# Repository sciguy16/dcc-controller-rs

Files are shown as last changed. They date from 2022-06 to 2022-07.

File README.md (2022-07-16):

# dcc-controller-rs
Open source lightweight DCC controller with firmware written in Rust

Based on the STM32F103C8T6 "blue pill" board - specifically the C8 version
rather than the C6 because the former has 64k of flash, and the graphics
components push the binary size up to around 51k.

DCC controller with an N gauge BR pannier tank

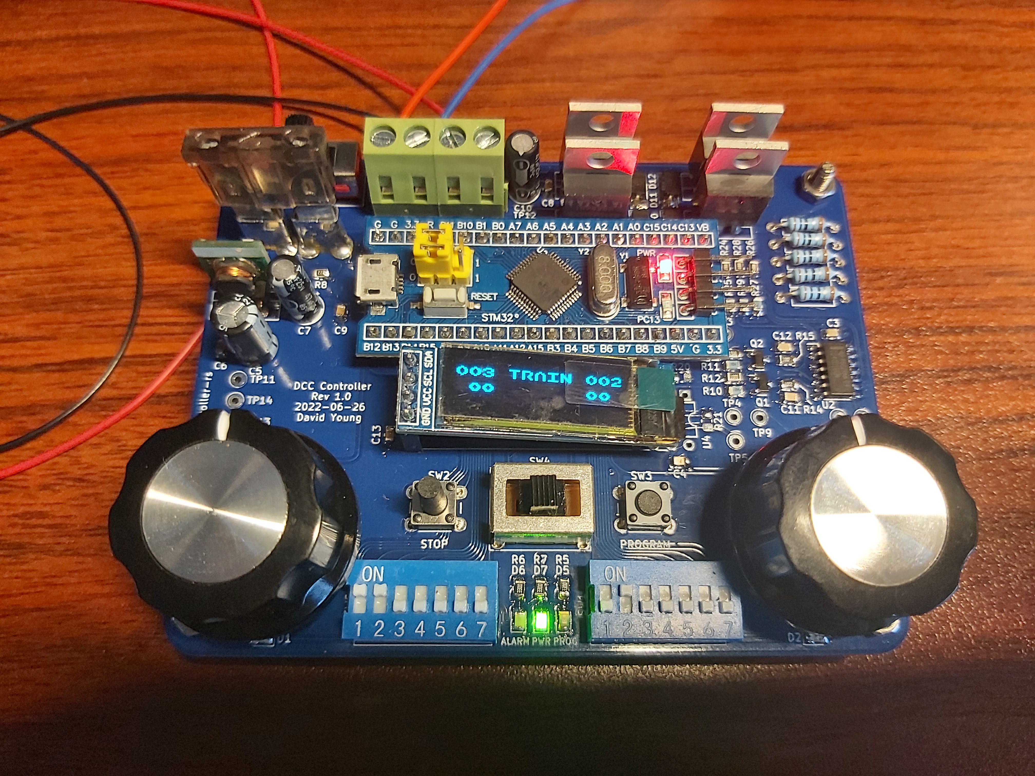
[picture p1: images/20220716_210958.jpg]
Overview of DCC controller


## Features
* Two control potentiometers to control two locomotives, with short-mode
addresses selected via dipswitches
* Potentiometers are centre-off; rotate left to drive the corresponding
locomotive in reverse, and right to drive it forwards
* LED for each channel to show when it is active
* On-off-on mini slide switch to select programming mode
  * programming mode disables all control functions and just sends out
DCC IDLE packets until the "program" button is pressed
  * Controller will then send out the programming sequence to program the
locomotive with the address set on the selected channel
* Current measurement and overcurrent shut-off
* Overcurrent alarm LED
* Screw terminals to connect power supply and track outputs
* Pure-Rust open source firmware based on dcc-rs
* Open source hardware

## Installation
Ensure that the `thumbv7m-none-eabi` target and the `probe-run` tool have
been installed and then `cargo run --release` will automatically flash the
compiled firmware onto the device.

```bash
rustup target add thumbv7m-none-eabi
cargo install probe-run
cargo run --release
DEFMT_LOG=off cargo run --release # Disable defmt logging
```

# License
Source code for the software components is distributed under the terms
of the Mozilla Public License Version 2.0.

Design files for the hardware components are distributed under the terms
of the CERN Open Hardware Licence Version 2 - Weakly Reciprocal.

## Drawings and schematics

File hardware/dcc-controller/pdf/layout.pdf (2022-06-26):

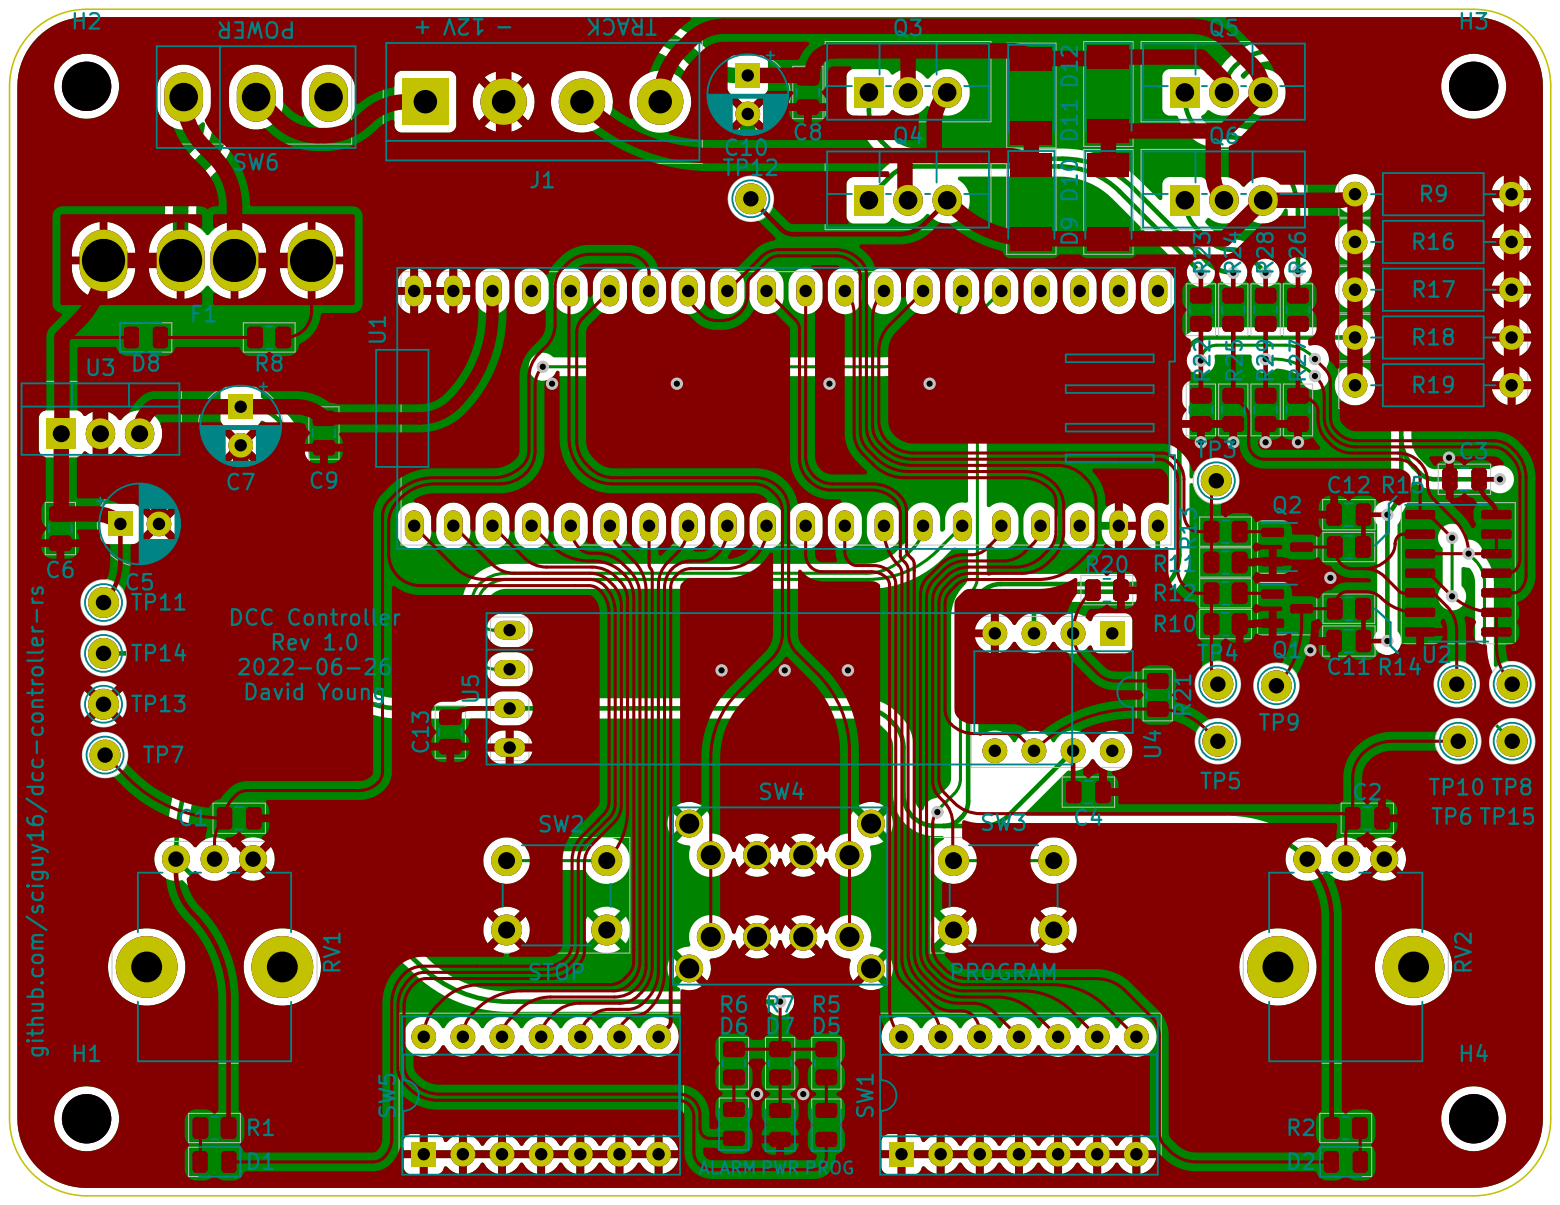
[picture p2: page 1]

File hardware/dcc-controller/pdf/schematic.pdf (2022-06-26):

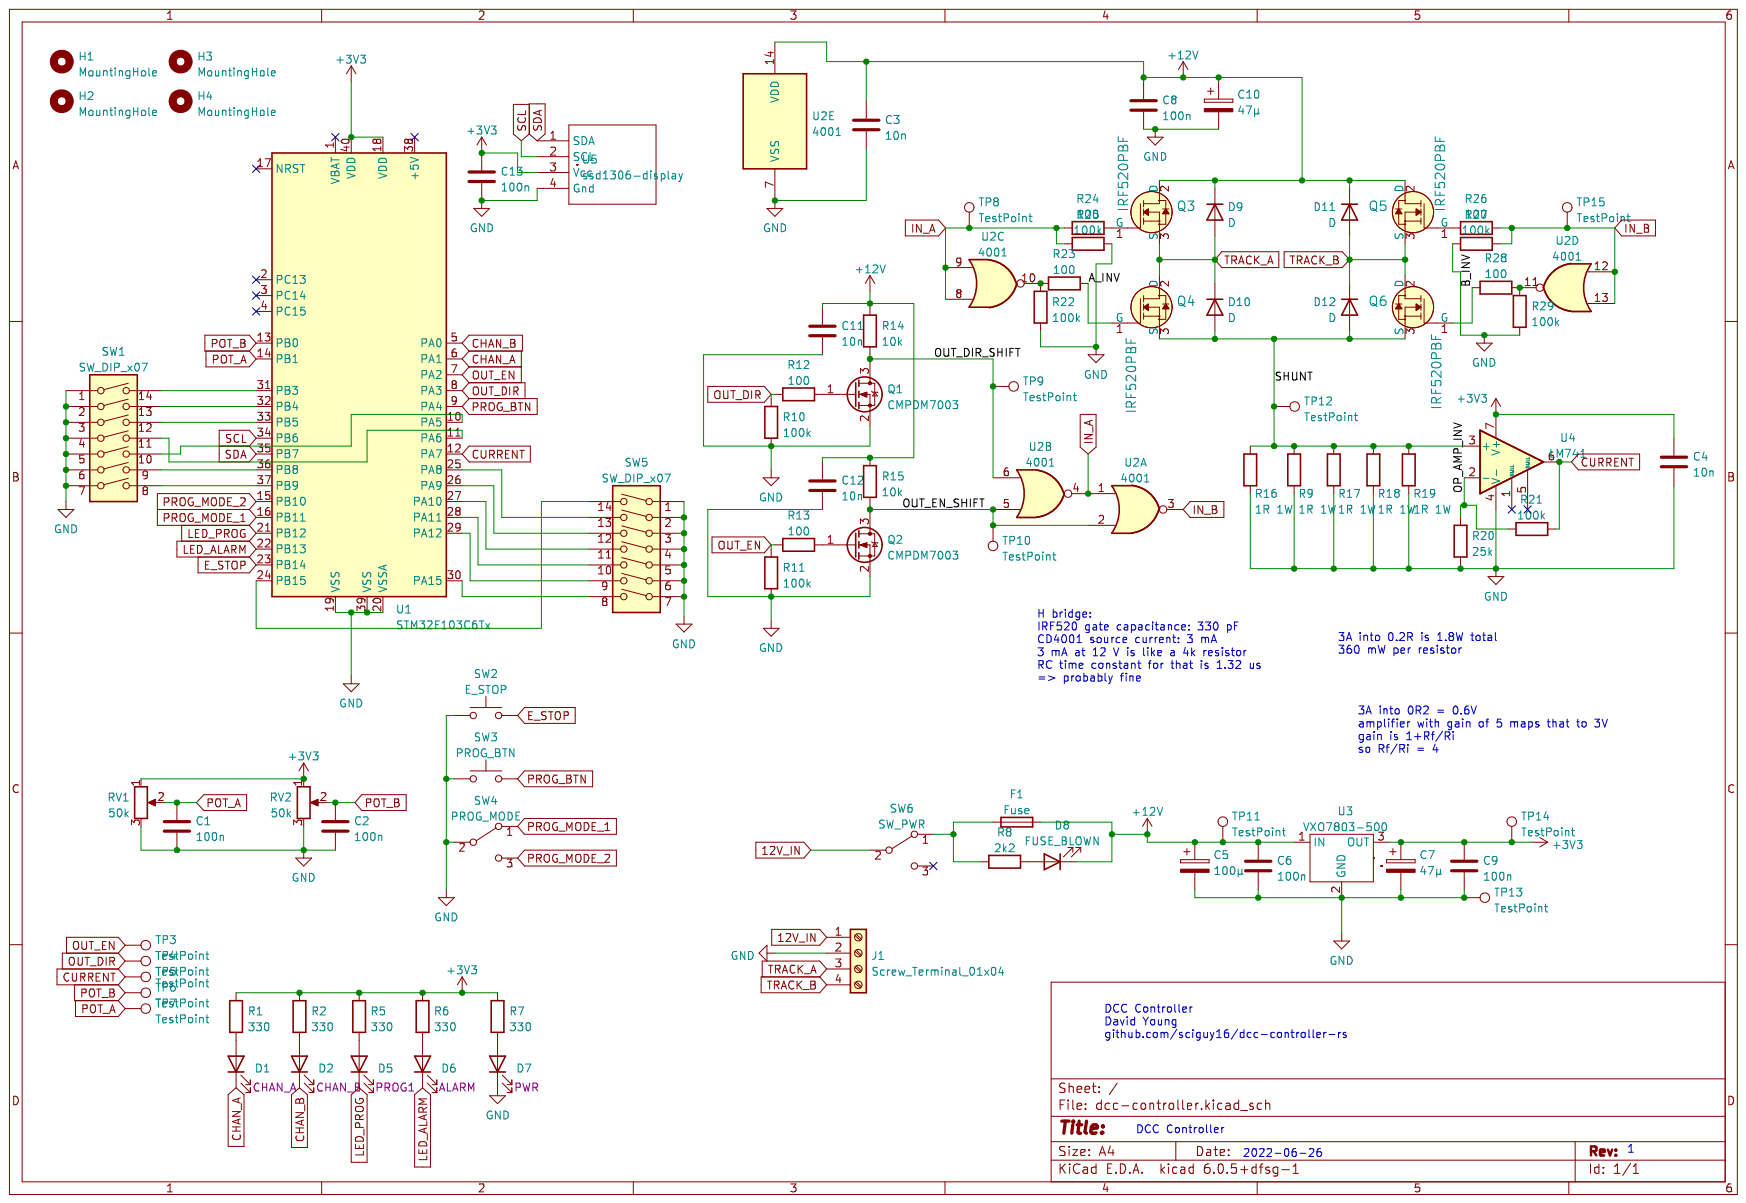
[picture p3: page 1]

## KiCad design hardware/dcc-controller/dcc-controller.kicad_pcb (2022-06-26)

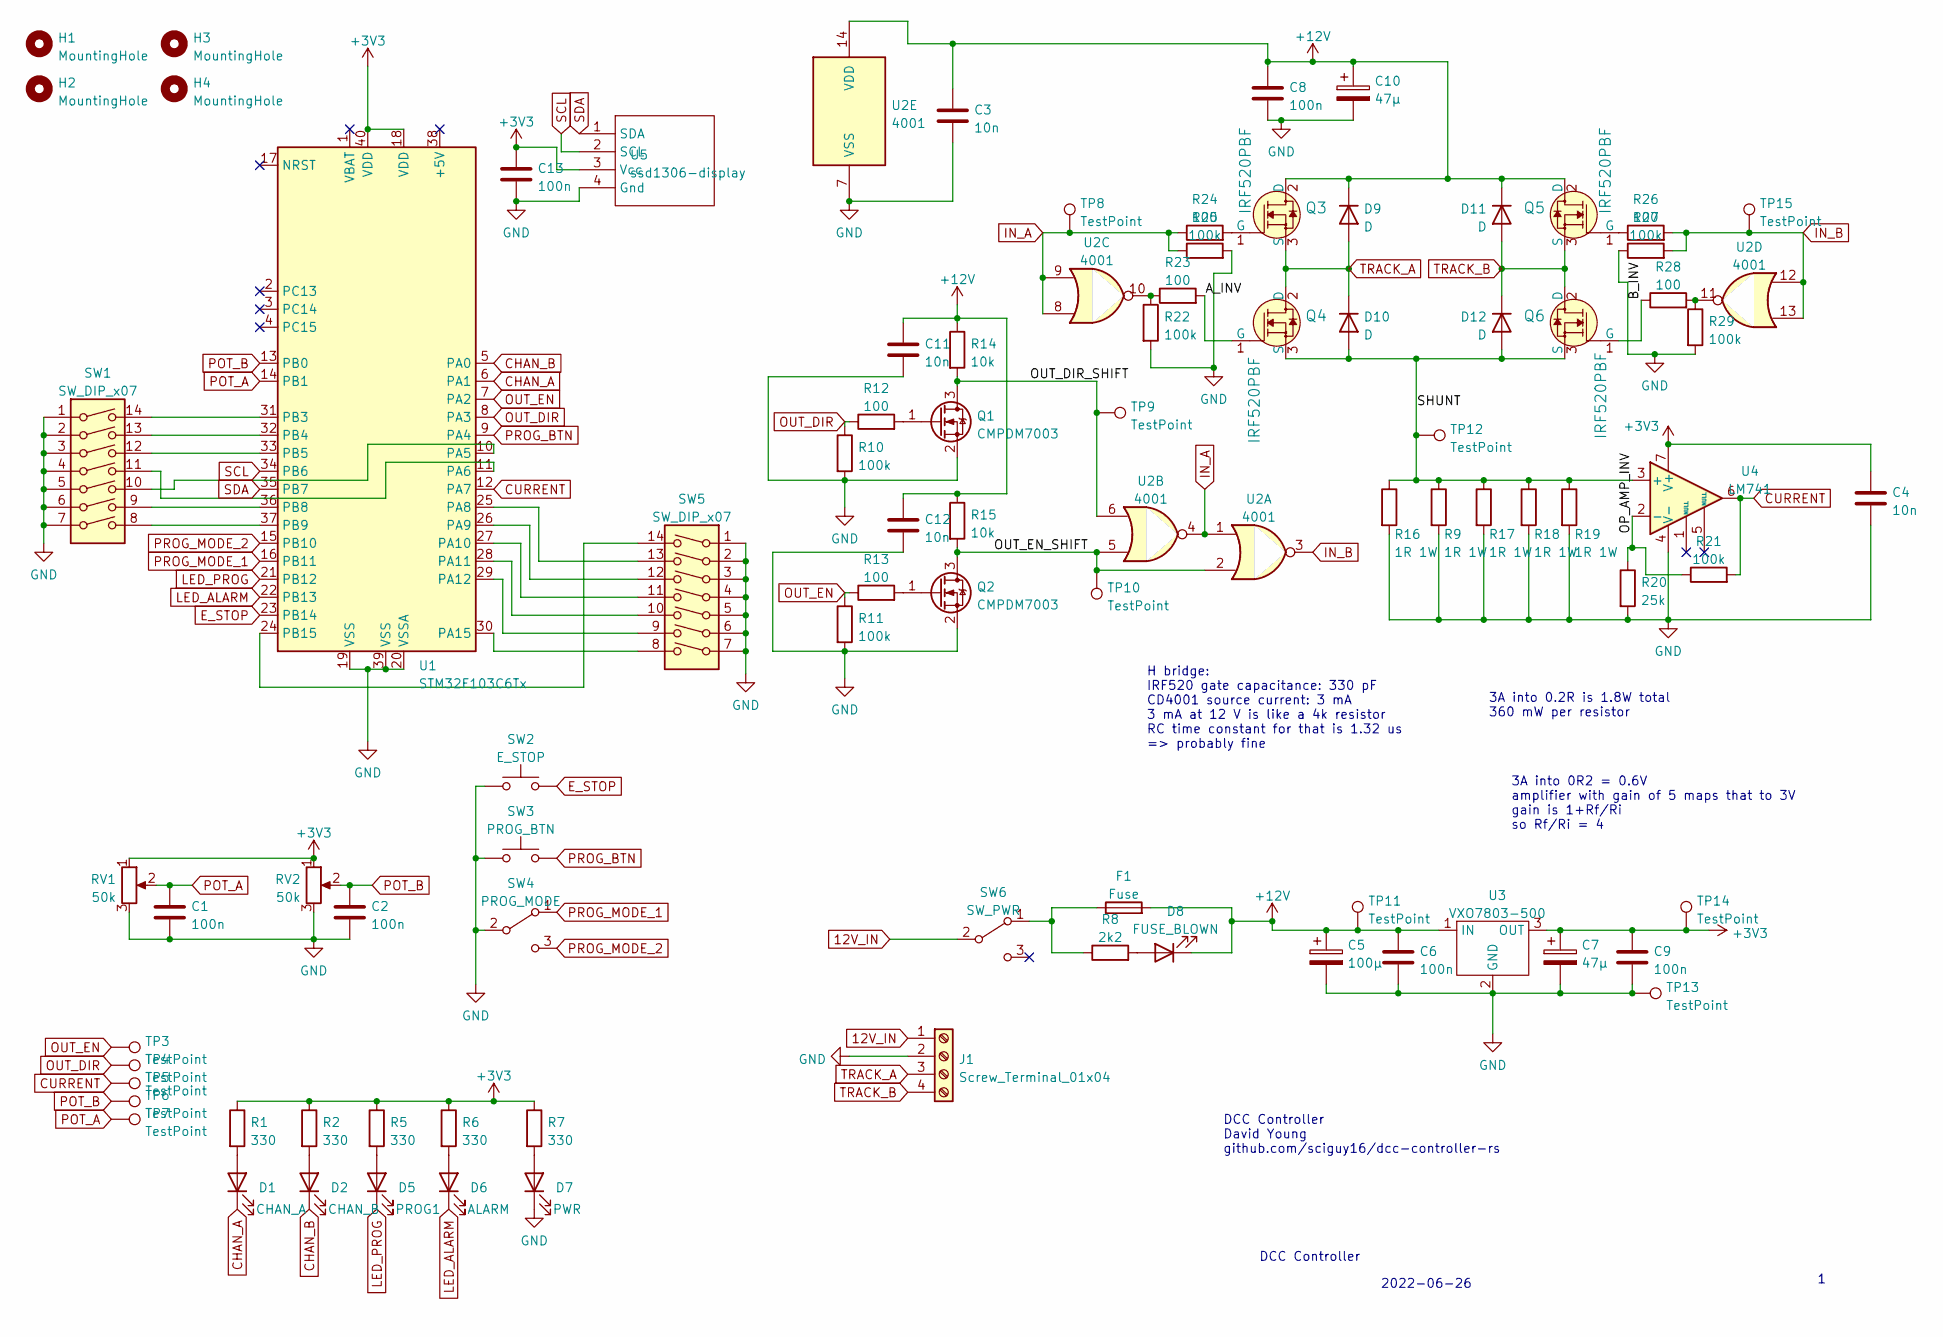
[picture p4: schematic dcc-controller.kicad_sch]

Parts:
C1, C2, C6, C8, C9, C13: 100n; C_0805_2012Metric
C3, C4, C11, C12: 10n; C_0805_2012Metric
C5: 100µ; CP_Radial_D5.0mm_P2.50mm
C7, C10: 47µ; CP_Radial_D5.0mm_P2.50mm
D1: CHAN_A; LED_0805_2012Metric
D2: CHAN_B; LED_0805_2012Metric
D5: PROG; LED_0805_2012Metric
D6: ALARM; LED_0805_2012Metric
D7: PWR; LED_0805_2012Metric
D8: FUSE_BLOWN; LED_0805_2012Metric
D9, D10, D11, D12: D; D_MELF
F1: Fuse; automotive-fuse-mount
H1, H2, H3, H4: MountingHole; MountingHole_3.2mm_M3
J1: Screw_Terminal_01x04; TerminalBlock_bornier-4_P5.08mm
Q1, Q2: CMPDM7003; SOT-23
Q3, Q4, Q5, Q6: IRF520PBF; TO-220F-3_Vertical; MPN IRF510PBF; Digi-Key_PN IRF510PBF-ND
R1, R2, R5, R6, R7: 330; R_0805_2012Metric
R8: 2k2; R_0805_2012Metric
R9, R16, R17, R18, R19: 1R 1W; R_Axial_DIN0207_L6.3mm_D2.5mm_P10.16mm_Horizontal
R10, R11, R21, R22, R25, R27, R29: 100k; R_0805_2012Metric
R12, R13, R23, R24, R26, R28: 100; R_0805_2012Metric
R14, R15: 10k; R_0805_2012Metric
R20: 25k; R_0805_2012Metric
RV1, RV2: 50k; Potentiometer_Bourns_PTV09A-1_Single_Vertical
SW1, SW5: SW_DIP_x07; DIP-14_W7.62mm_Socket
SW2: E_STOP; SW_PUSH_6mm_H5mm
SW3: PROG_BTN; SW_PUSH_6mm_H5mm
SW4: PROG_MODE; dp3t
SW6: SW_PWR; spdt-slide-switch
TP3, TP4, TP5, TP6, TP7, TP8, TP9, TP10, TP11, TP12, TP13, TP14, TP15: TestPoint; TestPoint_THTPad_D2.0mm_Drill1.0mm
U1: STM32F103C6Tx; stm32-blue-pill
U2: 4001; SOIC-14_3.9x8.7mm_P1.27mm
U3: VXO7803-500; TO-220-3_Vertical
U4: LM741; DIP-8_W7.62mm
U5: ssd1306-display

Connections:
12V_IN: J1.1, SW6.2 (B)
+3V3: C4.2, C7.1, C9.1, C13.1, R1.1, R2.1, R5.1, R6.1, R7.1, RV1.1, RV2.1, TP14.1, U1.18 (VDD), U1.40 (VDD), U3.3 (OUT), U4.7 (V+), U5.3 (Vcc)
+12V: C3.1, C5.1, C6.1, C8.2, C10.1, C11.1, C12.1, D8.1 (K), D9.1 (K), D11.1 (K), F1.2, Q3.2 (D), Q5.2 (D), R14.1, R15.1, TP11.1, U2.14 (VDD), U3.1 (IN)
/A_INV: Q4.1 (G), R23.2
/B_INV: Q6.1 (G), R28.1
/OP_AMP_INV: R20.1, R21.1, U4.2 (-)
/OUT_DIR_SHIFT: Q1.3 (D), R14.2, TP9.1, U2.6
/OUT_EN_SHIFT: Q2.3 (D), R15.2, TP10.1, U2.2, U2.5
/SHUNT: D10.2 (A), D12.2 (A), Q4.3 (S), Q6.3 (S), R9.1, R16.1, R17.1, R18.1, R19.1, TP12.1, U4.3 (+)
CHAN_A: D1.1 (K), U1.6 (PA1)
CHAN_B: D2.1 (K), U1.5 (PA0)
CURRENT: R21.2, TP5.1, U1.12 (PA7), U4.6
E_STOP: SW2.2, U1.23 (PB14)
GND: C1.2, C2.2, C3.2, C4.1, C5.2, C6.2, C7.2, C8.1, C9.2, C10.2, C11.2, C12.2, C13.2, D7.1 (K), J1.2, Q1.2 (S), Q2.2 (S), R9.2, R10.2, R11.2, R16.2, R17.2, R18.2, R19.2, R20.2, R22.2, R25.2, R27.1, R29.2, RV1.3, RV2.3, SW1.1, SW1.2, SW1.3, SW1.4, SW1.5, SW1.6, SW1.7, SW2.1, SW3.1, SW4.2 (B), SW5.1, SW5.2, SW5.3, SW5.4, SW5.5, SW5.6, SW5.7, TP13.1, U1.19 (VSS), U1.20 (VSSA), U1.39 (VSS), U2.7 (VSS), U3.2 (GND), U4.4 (V-), U5.4 (Gnd)
IN_A: R24.1, R25.1, TP8.1, U2.1, U2.4, U2.8, U2.9
IN_B: R26.2, R27.2, TP15.1, U2.3, U2.12, U2.13
LED_ALARM: D6.1 (K), U1.22 (PB13)
LED_PROG: D5.1 (K), U1.21 (PB12)
unnamed: D1.2 (A), R1.2
unnamed: D2.2 (A), R2.2
unnamed: D5.2 (A), R5.2
unnamed: D6.2 (A), R6.2
unnamed: D7.2 (A), R7.2
unnamed: D8.2 (A), R8.2
unnamed: F1.1, R8.1, SW6.1 (A)
unnamed: Q1.1 (G), R12.2
unnamed: Q2.1 (G), R13.2
unnamed: Q3.1 (G), R24.2
unnamed: Q5.1 (G), R26.1
unnamed: R22.1, R23.1, U2.10
unnamed: R28.2, R29.1, U2.11
unnamed: SW1.8, U1.37 (PB9)
unnamed: SW1.9, U1.36 (PB8)
unnamed: SW1.10, U1.10 (PA5)
unnamed: SW1.11, U1.11 (PA6)
unnamed: SW1.12, U1.33 (PB5)
unnamed: SW1.13, U1.32 (PB4)
unnamed: SW1.14, U1.31 (PB3)
unnamed: SW5.8, U1.30 (PA15)
unnamed: SW5.9, U1.29 (PA12)
unnamed: SW5.10, U1.28 (PA11)
unnamed: SW5.11, U1.27 (PA10)
unnamed: SW5.12, U1.26 (PA9)
unnamed: SW5.13, U1.25 (PA8)
unnamed: SW5.14, U1.24 (PB15)
OUT_DIR: R10.1, R12.1, TP4.1, U1.8 (PA3)
OUT_EN: R11.1, R13.1, TP3.1, U1.7 (PA2)
POT_A: C1.1, RV1.2, TP7.1, U1.14 (PB1)
POT_B: C2.1, RV2.2, TP6.1, U1.13 (PB0)
PROG_BTN: SW3.2, U1.9 (PA4)
PROG_MODE_1: SW4.1 (A), U1.16 (PB11)
PROG_MODE_2: SW4.3 (C), U1.15 (PB10)
SCL: U1.34 (PB6), U5.2 (SCL)
SDA: U1.35 (PB7), U5.1 (SDA)
TRACK_A: D9.2 (A), D10.1 (K), J1.3, Q3.3 (S), Q4.2 (D)
TRACK_B: D11.2 (A), D12.1 (K), J1.4, Q5.3 (S), Q6.2 (D)

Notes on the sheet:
DCC Controller
H bridge: IRF520 gate capacitance: 330 pF CD4001 source current: 3 mA 3 mA at 12 V is like a 4k resistor RC time constant for that is 1.32 us => probably fine
DCC Controller David Young github.com/sciguy16/dcc-controller-rs
2022-06-26
3A into 0.2R is 1.8W total 360 mW per resistor
3A into 0R2 = 0.6V amplifier with gain of 5 maps that to 3V gain is 1+Rf/Ri so Rf/Ri = 4

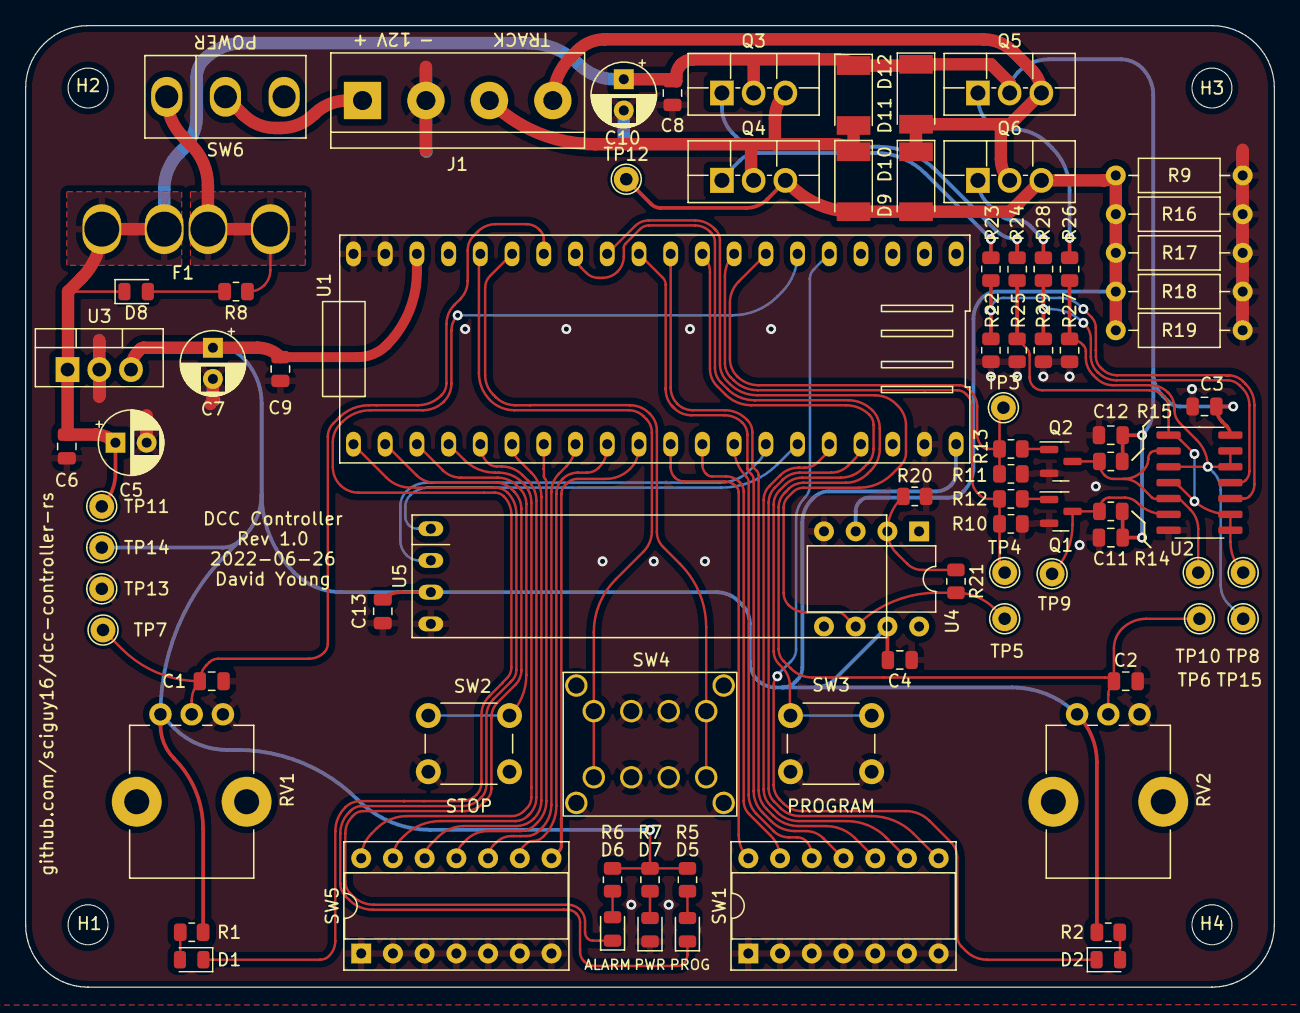
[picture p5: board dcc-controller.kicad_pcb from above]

Board: 2 copper layers, 100.0 x 77.0 mm, 88 parts (0 on the bottom side), 56 nets.

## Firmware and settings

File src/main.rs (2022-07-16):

// This Source Code Form is subject to the terms of the Mozilla Public
// License, v. 2.0. If a copy of the MPL was not distributed with this
// file, you can obtain one at https://mozilla.org/MPL/2.0/.

// Pinout:
// POT_LEFT: PB0
// POT_RIGHT: PB1
// DIPSW_LEFT: PB15, PA8, PA9, PA10, PA11, PA12, PA15
// DIPSW_RIGHT: PB3, PB4, PB5, PA6, PA5, PB8, PB9
// SCL: PB6
// SDA: PB7
// LED_LEFT: PA1
// LED_RIGHT: PA0
// LED_PROG: PB12
// LED_ALARM: PB13
// BTN_STOP: PB14
// BTN_PROG: PA4
// SW_PROG_LEFT: PB10
// SW_PROG_RIGHT: PB11
// OUT_EN: PA2
// OUT_DIR: PA3
// CURRENT_SENSE: PA7

#![no_main]
#![no_std]

use crate::hal::{
    adc,
    gpio::{gpioa, gpiob, Output, PushPull},
    i2c::{BlockingI2c, Mode},
    pac::{interrupt, Interrupt, Peripherals, TIM2},
    prelude::*,
    timer::{CounterUs, Event},
};
use core::cell::RefCell;
use core::fmt::{self, Display, Formatter, Write};
use core::panic::PanicInfo;
use cortex_m::interrupt::Mutex;
use cortex_m_rt::entry;
use dcc_rs::{packets::*, DccInterruptHandler};
use defmt::{debug, info};
use defmt_rtt as _;
use embedded_graphics::{
    mono_font::{ascii, MonoTextStyleBuilder},
    pixelcolor::BinaryColor,
    prelude::*,
    text::{Baseline, Text},
};
use ssd1306::{prelude::*, Ssd1306};
use stm32f1xx_hal as hal;

mod address_switches;

use address_switches::AddressSwitches;

const CLOCK_MHZ: u32 = 48;

#[derive(Default)]
struct ChannelProps {
    address: u8,
    speed: u8,
    direction: Direction,
}

impl ChannelProps {
    pub fn with_address(address: u8) -> Self {
        Self {
            address,
            ..Default::default()
        }
    }

    pub fn direction_arrow(&self) -> char {
        match (self.speed, self.direction) {
            (0, _) => ' ',
            (_, Direction::Forward) => '>',
            (_, Direction::Backward) => '<',
        }
    }
}

#[derive(Copy, Clone)]
enum Channel {
    Left,
    Right,
}

impl Channel {
    pub fn swap(self) -> Self {
        match self {
            Channel::Left => Channel::Right,
            Channel::Right => Channel::Left,
        }
    }
}

impl Display for Channel {
    fn fmt(&self, fmt: &mut Formatter) -> fmt::Result {
        write!(
            fmt,
            "{}",
            match self {
                Channel::Left => "LEFT",
                Channel::Right => "RIGHT",
            }
        )
    }
}

enum RunState {
    /// Run state tracks the channel and alternates between them
    Run(Channel),
    Prog(Channel),
    EmergencyStop,
}

#[panic_handler]
fn panic(_: &PanicInfo) -> ! {
    // Turn off outputs
    cortex_m::interrupt::free(|cs| {
        if let Some(out_en) = LED_ALARM.borrow(cs).borrow_mut().as_mut() {
            out_en.set_low();
        }
    });

    // grab alarm LED and turn it on
    let mut led = cortex_m::interrupt::free(|cs| {
        LED_ALARM.borrow(cs).borrow_mut().take()
    });
    if let Some(led) = &mut led {
        led.set_low();
    }
    loop {
        // Counting nops here doesn't give a precise timing because the
        // DCC timer is still running
        for _ in 0..CLOCK_MHZ * 10_000 {
            unsafe {
                core::arch::asm!("nop");
            }
        }
        if let Some(led) = &mut led {
            led.toggle();
        }
    }
}

// A type definition for the GPIO pin to be used for our LED
type DccDirPin = gpioa::PA3<Output<PushPull>>;

// Make DCC thingy globally available
static G_DCC: Mutex<RefCell<Option<DccInterruptHandler<DccDirPin>>>> =
    Mutex::new(RefCell::new(None));

// Make timer interrupt registers globally available
static G_TIM: Mutex<RefCell<Option<CounterUs<TIM2>>>> =
    Mutex::new(RefCell::new(None));

// place for sending packets
static TX_BUFFER: Mutex<RefCell<Option<(SerialiseBuffer, usize)>>> =
    Mutex::new(RefCell::new(None));

type LedAlarm = gpiob::PB13<Output<PushPull>>;
static LED_ALARM: Mutex<RefCell<Option<LedAlarm>>> =
    Mutex::new(RefCell::new(None));

type EnablePin = gpioa::PA2<Output<PushPull>>;
static ENABLE_PIN: Mutex<RefCell<Option<EnablePin>>> =
    Mutex::new(RefCell::new(None));

#[interrupt]
fn TIM2() {
    static mut DCC: Option<DccInterruptHandler<DccDirPin>> = None;
    static mut TIM: Option<CounterUs<TIM2>> = None;

    let dcc = DCC.get_or_insert_with(|| {
        cortex_m::interrupt::free(|cs| {
            // Move LED pin here, leaving a None in its place
            G_DCC.borrow(cs).replace(None).unwrap()
        })
    });

    let tim = TIM.get_or_insert_with(|| {
        cortex_m::interrupt::free(|cs| {
            // Move LED pin here, leaving a None in its place
            G_TIM.borrow(cs).replace(None).unwrap()
        })
    });

    if let Some((new_data, len)) =
        cortex_m::interrupt::free(|cs| TX_BUFFER.borrow(cs).replace(None))
    {
        dcc.write(&new_data[..len]).unwrap();
    }

    if let Ok(new_delay) = dcc.tick() {
        tim.start(new_delay.micros()).unwrap();
    }

    let _ = tim.wait();
}

#[entry]
fn main() -> ! {
    info!("Start boot");

    let dp = Peripherals::take().unwrap();
    let mut cp = cortex_m::Peripherals::take().unwrap();

    let rcc = dp.RCC.constrain();
    let mut flash = dp.FLASH.constrain();

    // Prepare the alternate function I/O registers
    let mut afio = dp.AFIO.constrain();
    // let clocks = rcc.cfgr.freeze(&mut flash.acr);
    let clocks = rcc
        .cfgr
        .use_hse(8.MHz())
        .sysclk(CLOCK_MHZ.MHz())
        //.pclk1(8.MHz())
        .freeze(&mut flash.acr);
    // info!("adc freq: {}", clocks.adcclk());

    let mut gpioa = dp.GPIOA.split();
    let mut gpiob = dp.GPIOB.split();

    // store the alarm led pin so that it is available for the panic handler
    let mut led_alarm = gpiob.pb13.into_push_pull_output(&mut gpiob.crh);
    led_alarm.set_high();
    cortex_m::interrupt::free(|cs| {
        *LED_ALARM.borrow(cs).borrow_mut() = Some(led_alarm)
    });

    info!("Initialise DCC interrupt handler");
    let dcc_pin = gpioa.pa3.into_push_pull_output(&mut gpioa.crl);
    let dcc = DccInterruptHandler::new(dcc_pin);
    cortex_m::interrupt::free(|cs| *G_DCC.borrow(cs).borrow_mut() = Some(dcc));

    info!("Initialise timer");
    let mut timer = dp.TIM2.counter_us(&clocks);
    // Generate an interrupt when the timer expires
    timer.start(50000.micros()).unwrap();
    timer.listen(Event::Update);
    cortex_m::interrupt::free(|cs| {
        *G_TIM.borrow(cs).borrow_mut() = Some(timer)
    });

    info!("Init I2C");
    cp.DWT.enable_cycle_counter();
    let scl = gpiob.pb6.into_alternate_open_drain(&mut gpiob.crl);
    let sda = gpiob.pb7.into_alternate_open_drain(&mut gpiob.crl);
    let i2c = BlockingI2c::i2c1(
        dp.I2C1,
        (scl, sda),
        &mut afio.mapr,
        Mode::Standard {
            frequency: 400.kHz(),
        },
        clocks,
        1000,
        10,
        1000,
        1000,
    );

    info!("Init display");
    let interface = ssd1306::I2CDisplayInterface::new(i2c);
    let mut display =
        Ssd1306::new(interface, DisplaySize128x64, DisplayRotation::Rotate0)
            .into_buffered_graphics_mode();
    display.init().unwrap();

    // Create a text style for drawing the font:
    let text_style = MonoTextStyleBuilder::new()
        .font(&ascii::FONT_10X20)
        .text_color(BinaryColor::On)
        .build();

    //enable TIM2 interrupt
    unsafe {
        cortex_m::peripheral::NVIC::unmask(Interrupt::TIM2);
    }

    // make a delay thing to send packets
    let mut delay = cp.SYST.delay(&clocks);

    // LED to show when power is on
    let mut led1 = gpioa.pa1.into_push_pull_output(&mut gpioa.crl);
    let mut led2 = gpioa.pa0.into_push_pull_output(&mut gpioa.crl);
    let mut led_prog = gpiob.pb12.into_push_pull_output(&mut gpiob.crh);
    led1.set_high();
    led2.set_high();
    led_prog.set_high();

    let mut out_en = gpioa.pa2.into_push_pull_output(&mut gpioa.crl);
    out_en.set_high();
    cortex_m::interrupt::free(|cs| {
        *ENABLE_PIN.borrow(cs).borrow_mut() = Some(out_en)
    });

    // remove pins from the jtag peripheral and set up pins for address
    // selectors
    info!("Set up address pins");
    let (pa15, pb3, pb4) =
        afio.mapr.disable_jtag(gpioa.pa15, gpiob.pb3, gpiob.pb4);
    let mut addr_left = AddressSwitches::new(
        gpiob.pb15.into_pull_up_input(&mut gpiob.crh),
        gpioa.pa8.into_pull_up_input(&mut gpioa.crh),
        gpioa.pa9.into_pull_up_input(&mut gpioa.crh),
        gpioa.pa10.into_pull_up_input(&mut gpioa.crh),
        gpioa.pa11.into_pull_up_input(&mut gpioa.crh),
        gpioa.pa12.into_pull_up_input(&mut gpioa.crh),
        pa15.into_pull_up_input(&mut gpioa.crh),
    );
    let mut addr_right = AddressSwitches::new(
        pb3.into_pull_up_input(&mut gpiob.crl),
        pb4.into_pull_up_input(&mut gpiob.crl),
        gpiob.pb5.into_pull_up_input(&mut gpiob.crl),
        gpioa.pa6.into_pull_up_input(&mut gpioa.crl),
        gpioa.pa5.into_pull_up_input(&mut gpioa.crl),
        gpiob.pb8.into_pull_up_input(&mut gpiob.crh),
        gpiob.pb9.into_pull_up_input(&mut gpiob.crh),
    );
    info!(
        "addresses: left={}, right={}",
        addr_left.value(),
        addr_right.value()
    );

    info!("Configure button pins");
    let btn_stop = gpiob.pb14.into_pull_up_input(&mut gpiob.crh);
    let btn_prog = gpioa.pa4.into_pull_up_input(&mut gpioa.crl);
    let sw_prog_left = gpiob.pb11.into_pull_up_input(&mut gpiob.crh);
    let sw_prog_right = gpiob.pb10.into_pull_up_input(&mut gpiob.crh);

    // set up ADC
    info!("Configure ADC");
    let mut adc1 = adc::Adc::adc1(dp.ADC1, clocks);
    let mut ch0 = gpiob.pb1.into_analog(&mut gpiob.crl);
    let mut ch1 = gpiob.pb0.into_analog(&mut gpiob.crl);

    let mut adc2 = adc::Adc::adc2(dp.ADC2, clocks);
    let mut current_pin = gpioa.pa7.into_analog(&mut gpioa.crl);

    let mut chan_left = ChannelProps::with_address(addr_left.value());
    let mut chan_right = ChannelProps::with_address(addr_right.value());

    let mut row1 = FmtBuf::new();
    let mut row2 = FmtBuf::new();

    let mut run_state = RunState::Run(Channel::Left);

    info!("Enter main loop");
    loop {
        // read the current
        let current: u16 = adc2.read(&mut current_pin).unwrap();

        // update address
        addr_left.update();
        addr_right.update();

        run_state = match run_state {
            RunState::Run(chan) => {
                use Channel::*;

                // read the control
                let control: u16 = match chan {
                    Left => adc1.read(&mut ch0).unwrap(),
                    Right => adc1.read(&mut ch1).unwrap(),
                };

                // it's a 12-bit ADC, range is 0..=4095
                // speed is -16..=16
                // use the following ranges:
                // 0..1600: -16..0
                // 2495..=4095: 0..=16
                // 1601..2495: 0
                let (speed, direction) = match control {
                    0..=1600 => (28 - control / 57, Direction::Backward),
                    2495..=4095 => ((control - 2494) / 57, Direction::Forward),
                    _ => (0, Direction::Forward),
                };
                // info!(
                //     "control {} set to: {}, speed is {} {}",
                //     channel_select as u8, control, speed, direction
                // );
                let speed = (speed & 0x1f) as u8;
                match (speed, chan) {
                    (0, Left) => led1.set_high(),
                    (0, Right) => led2.set_high(),
                    (_, Left) => led1.set_low(),
                    (_, Right) => led2.set_low(),
                };

                let loco_addr = match chan {
                    Left => {
                        chan_left.speed = speed;
                        chan_left.direction = direction;
                        addr_left.value()
                    }
                    Right => {
                        chan_right.speed = speed;
                        chan_right.direction = direction;
                        addr_right.value()
                    }
                };

                //info!("tx, addr = {}", addr);
                // pop a new chunk of data into the buffer
                let pkt = SpeedAndDirection::builder()
                    .address(loco_addr)
                    .unwrap()
                    .speed(speed)
                    .unwrap()
                    .direction(direction)
                    .build();
                let mut buffer = SerialiseBuffer::default();
                let len = pkt.serialise(&mut buffer).unwrap();
                cortex_m::interrupt::free(|cs| {
                    *TX_BUFFER.borrow(cs).borrow_mut() = Some((buffer, len))
                });

                debug!(
                    "Speed {}: {}, speed {}: {}, current: {}",
                    chan_left.address,
                    chan_left.speed,
                    chan_right.address,
                    chan_right.speed,
                    current
                );

                // Display is 128 x 64
                // Font is 10x20
                //
                // 000  loco  000
                //
                // >05>      >04>
                //

                row1.reset();
                write!(
                    &mut row1,
                    "{:03} TRAIN {:03}",
                    addr_left.value(),
                    addr_right.value()
                )
                .unwrap();

                row2.reset();
                {
                    let a = chan_left.direction_arrow();
                    let b = chan_right.direction_arrow();
                    write!(
                        &mut row2,
                        "{a}{speed1:02}{a}     {b}{speed2:02}{b}",
                        speed1 = chan_left.speed,
                        speed2 = chan_right.speed,
                    )
                }
                .unwrap();

                delay.delay_ms(10u16);

                // decide the next state
                if btn_stop.is_low() {
                    info!("Emergency stop!");
                    RunState::EmergencyStop
                } else if sw_prog_left.is_low() {
                    info!("Program mode LEFT");
                    RunState::Prog(Channel::Left)
                } else if sw_prog_right.is_low() {
                    info!("Program mode RIGHT");
                    RunState::Prog(Channel::Right)
                } else {
                    RunState::Run(chan.swap())
                }
            }
            RunState::Prog(chan) => {
                // Display programming mode on screen with address and
                // channel selection
                led_prog.set_low();

                row1.reset();
                row2.reset();
                write!(
                    &mut row1,
                    "{:03} TRAIN {:03}",
                    addr_left.value(),
                    addr_right.value()
                )
                .unwrap();
                write!(&mut row2, "PROG: {}", chan).unwrap();

                // handle pressing the "program" button
                if btn_prog.is_low() {
                    led_prog.set_high();
                    //TODO do program sequence
                }

                // decide the next state
                let left = sw_prog_left.is_high();
                let right = sw_prog_right.is_high();

                match (left, right) {
                    (true, true) => {
                        info!("RUN mode");
                        led_prog.set_high();
                        RunState::Run(Channel::Left)
                    }
                    (true, false) => RunState::Prog(Channel::Right),
                    (false, true) => RunState::Prog(Channel::Left),
                    (false, false) => {
                        // In theory it's impossible for the switch to
                        // be in both positions at the same time...
                        RunState::EmergencyStop
                    }
                }
            }
            RunState::EmergencyStop => {
                // disable outputs, draw "e-stop" on display and panic

                cortex_m::interrupt::free(|cs| {
                    if let Some(out_en) =
                        LED_ALARM.borrow(cs).borrow_mut().as_mut()
                    {
                        out_en.set_low();
                    }
                });

                row1.reset();
                row2.reset();
                write!(&mut row1, "STOP",).unwrap();

                // Empty the display:
                display.clear();

                // Draw 2 lines of text:
                Text::with_baseline(
                    row1.as_str(),
                    Point::new(0, 25),
                    text_style,
                    Baseline::Alphabetic,
                )
                .draw(&mut display)
                .unwrap();

                Text::with_baseline(
                    row2.as_str(),
                    Point::new(0, 50),
                    text_style,
                    Baseline::Alphabetic,
                )
                .draw(&mut display)
                .unwrap();

                display.flush().unwrap();

                panic!();
            }
        };

        // Update display from the text buffers
        display.clear();
        Text::with_baseline(
            row1.as_str(),
            Point::new(0, 25),
            text_style,
            Baseline::Alphabetic,
        )
        .draw(&mut display)
        .unwrap();
        Text::with_baseline(
            row2.as_str(),
            Point::new(0, 50),
            text_style,
            Baseline::Alphabetic,
        )
        .draw(&mut display)
        .unwrap();
        display.flush().unwrap();
    }
}

/// This is a very simple buffer to pre format a short line of text
/// limited arbitrarily to 64 bytes.
struct FmtBuf {
    buf: [u8; 64],
    ptr: usize,
}

impl FmtBuf {
    fn new() -> Self {
        Self {
            buf: [0; 64],
            ptr: 0,
        }
    }

    fn reset(&mut self) {
        self.ptr = 0;
    }

    fn as_str(&self) -> &str {
        core::str::from_utf8(&self.buf[0..self.ptr]).unwrap()
    }
}

impl core::fmt::Write for FmtBuf {
    fn write_str(&mut self, s: &str) -> core::fmt::Result {
        let rest_len = self.buf.len() - self.ptr;
        let len = if rest_len < s.len() {
            rest_len
        } else {
            s.len()
        };
        self.buf[self.ptr..(self.ptr + len)]
            .copy_from_slice(&s.as_bytes()[0..len]);
        self.ptr += len;
        Ok(())
    }
}

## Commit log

2022-06-15 List specifications and make empty kicad project
    [dcc-controller.kicad_pcb, dcc-controller.kicad_sch]
2022-06-18 Make schematic for controller
    [dcc-controller.kicad_sch]
2022-06-19 Inital layout
    [dcc-controller.kicad_pcb, dcc-controller.kicad_sch]
2022-06-24 Implement display functions and upgrade to STM32F103C8T6
2022-06-24 Update schematic for display
    [dcc-controller.kicad_pcb, dcc-controller.kicad_sch]
2022-06-25 Do layout and routing for new display version
    [dcc-controller.kicad_pcb, dcc-controller.kicad_sch]
2022-06-26 Tidy up routing
    [dcc-controller.kicad_pcb]
2022-06-26 Tidy up silkscreen
    [dcc-controller.kicad_pcb]
2022-06-26 Add gerbers and printouts
    [dcc-controller-B_Cu.gbr, dcc-controller-B_Mask.gbr, dcc-controller-B_Paste.gbr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]
2022-07-13 Update pin mappings for pcb
2022-07-14 Turn on alarm LED when panic
2022-07-14 Implement the address switches for the right channel
2022-07-15 Refactor address switch into module and make alarm light blink on panic
2022-07-16 Add description of STM32
